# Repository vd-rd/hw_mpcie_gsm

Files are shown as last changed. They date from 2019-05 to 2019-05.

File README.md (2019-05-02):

## Overview
Open Hardware Mini PCI Express GPS module for embedded communications or DIY projects.

### Specifications
 * Simcom SIM800 GSM modem

### Features
 * Compliant with the half mPCI Express mechanical and electrical specifications (rev 2.1)
 * Relatively easy to assemble at home (some experience with SMD soldering required)
 * No special driver required under Linux (exposed as CDC interface)
 * Separate .1inch breakout header for UART interfacing
 * Compliant with most cheap mPCI to USB solutions

### Resources
You can find all necesary information to build or evaluate the module here:
   - [View 3D board render](https://a360.co/2J9JpYO)
   - [Fabrication files](https://github.com/vd-rd/hw_mpcie_gsm/releases)

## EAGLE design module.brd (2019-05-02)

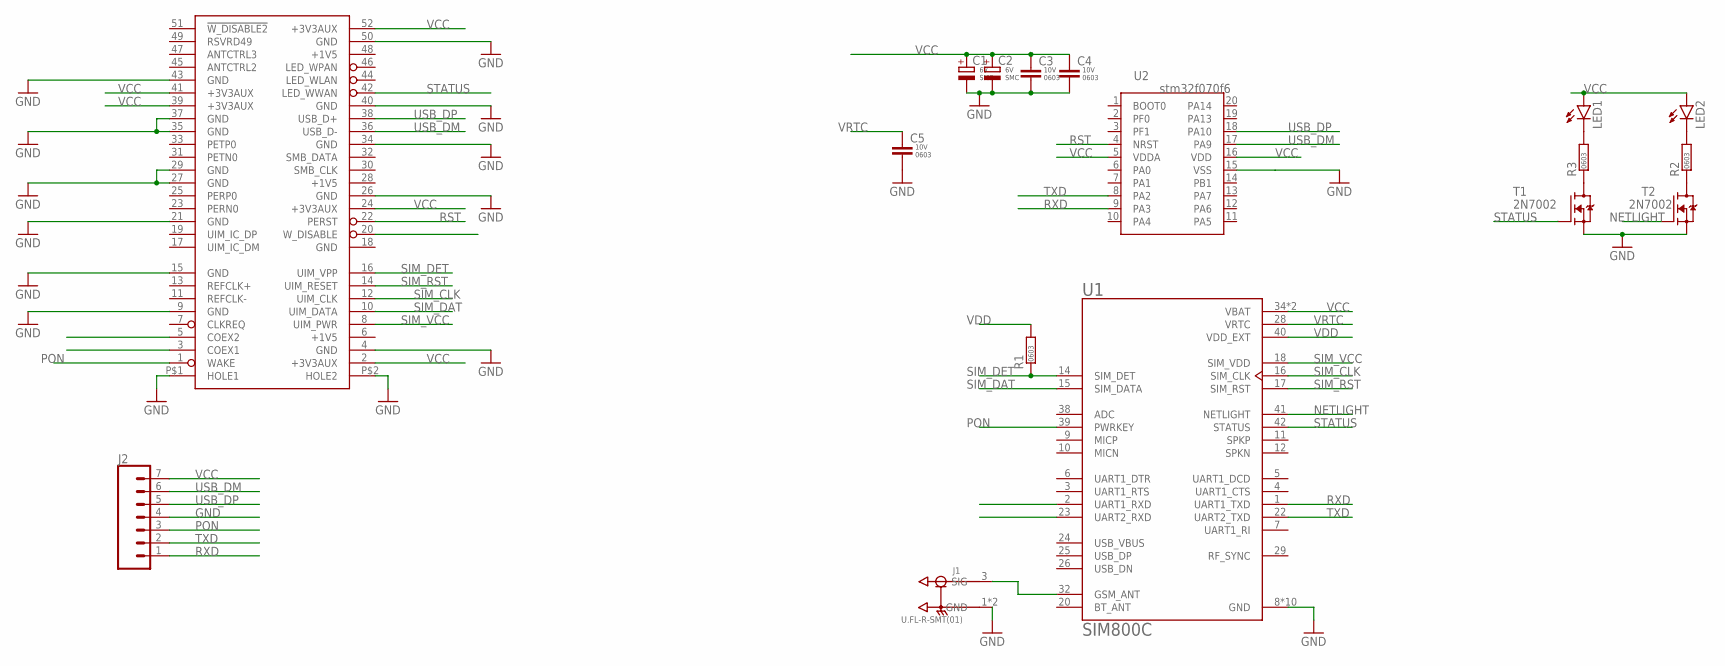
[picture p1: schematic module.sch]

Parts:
C1, C2: CAP-POL-SMC; SMC_C
C3, C4, C5: CAP-0603; C0603
FORM1: MPCIE_HALF
J1: U.FL-R-SMT(01); HRS_U.FL-R-SMT(01)
J2: CONN_07; 1X07
LED1, LED2: LEDCHIP-LED0603; CHIP-LED0603
R1, R2, R3: RES-0603; R0603
T1, T2: 2N7002; SOT95P240X110-3
U1: SIM800C; LCC110P1570X1760X250-42N
U2: STM32F070F6; SOP65P640X120-20

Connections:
+1V5: FORM1.6 (+1V5), FORM1.28 (+1V5)
GND: C1.-, C2.-, C3.2, C4.2, C5.2, FORM1.4 (GND), FORM1.9 (GND), FORM1.15 (GND), FORM1.18 (GND), FORM1.21 (GND), FORM1.26 (GND), FORM1.27 (GND), FORM1.29 (GND), FORM1.34 (GND), FORM1.35 (GND), FORM1.37 (GND), FORM1.40 (GND), FORM1.43 (GND), FORM1.50 (GND), FORM1.P$1 (HOLE1), FORM1.P$2 (HOLE2), J1.1 (GND), J1.2 (GND), J2.4, T1.2 (S), T2.2 (S), U1.8 (GND), U1.13 (GND), U1.19 (GND), U1.21 (GND), U1.27 (GND), U1.30 (GND), U1.31 (GND), U1.33 (GND), U1.36 (GND), U1.37 (GND), U2.15 (VSS)
unnamed: J1.3 (SIG), U1.32 (GSM_ANT)
unnamed: LED2.C, R2.2
unnamed: LED1.C, R3.2
unnamed: R3.1, T1.3 (D)
unnamed: R2.1, T2.3 (D)
NETLIGHT: T2.1 (G), U1.41 (NETLIGHT)
PON: FORM1.1 (WAKE), J2.3, U1.39 (PWRKEY)
RST: FORM1.22 (PERST), U2.4 (NRST)
RXD: J2.1, U1.1 (UART1_TXD), U2.9 (PA3)
SIM_CLK: FORM1.12 (UIM_CLK), U1.16 (SIM_CLK)
SIM_DAT: FORM1.10 (UIM_DATA), U1.15 (SIM_DATA)
SIM_DET: FORM1.16 (UIM_VPP), R1.1, U1.14 (SIM_DET)
SIM_RST: FORM1.14 (UIM_RESET), U1.17 (SIM_RST)
SIM_VCC: FORM1.8 (UIM_PWR), U1.18 (SIM_VDD)
SMB_DATA: FORM1.32 (SMB_DATA)
STATUS: FORM1.42 (LED_WWAN), T1.1 (G), U1.42 (STATUS)
TXD: J2.2, U1.22 (UART2_TXD), U2.8 (PA2)
USB_DM: FORM1.36 (USB_D-), J2.6, U2.17 (PA9)
USB_DP: FORM1.38 (USB_D+), J2.5, U2.18 (PA10)
VCC: C1.+, C2.+, C3.1, C4.1, FORM1.2 (+3V3AUX), FORM1.24 (+3V3AUX), FORM1.39 (+3V3AUX), FORM1.41 (+3V3AUX), FORM1.52 (+3V3AUX), J2.7, LED1.A, LED2.A, U1.34 (VBAT), U1.35 (VBAT), U2.5 (VDDA), U2.16 (VDD)
VDD: R1.2, U1.40 (VDD_EXT)
VRTC: C5.1, U1.28 (VRTC)

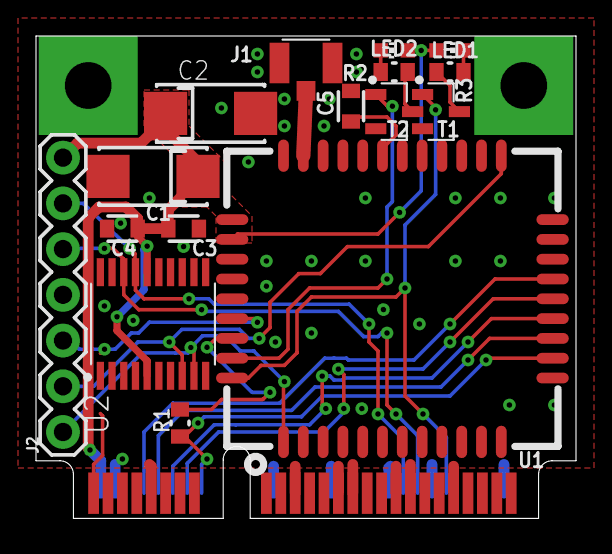
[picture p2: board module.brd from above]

Board: 2 copper layers, 30.0 x 26.8 mm, 17 parts (0 on the bottom side), 23 nets.

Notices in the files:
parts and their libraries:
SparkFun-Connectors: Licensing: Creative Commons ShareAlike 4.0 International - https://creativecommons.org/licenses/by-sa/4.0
